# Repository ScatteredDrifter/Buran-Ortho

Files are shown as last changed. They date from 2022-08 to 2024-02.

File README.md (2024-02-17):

# Buran-Ortho
A 39-key orthogonal keyboard with support for two knobs. 

Used License :: [Cern Open hardware](/LICENSE)

---



## Status :: 
- Rev 3 released
- Case options were updated accordingly 
- untested LED-Pinout 

---

## Features :: 
- PCB supports MX, Alps and Choc v1 switches  
- QMK and Vial Support
- built with rp2040 and additional flash storage allowing for plenty of combos, layers, led matrices etc.
- easy to order with jlcpcb --> check release for files 
- support up to two encoders 
- additional pinouts for further modifications 
- - technically could fit an OLED or some other additional parts
- gasket mounted case
- case designed for 3d printing 
- several layout-options for middle part.

## Layout :: 
Below all possible layouts can be observed. All the observed layouts can be choosen and used with Vial or Qmk 

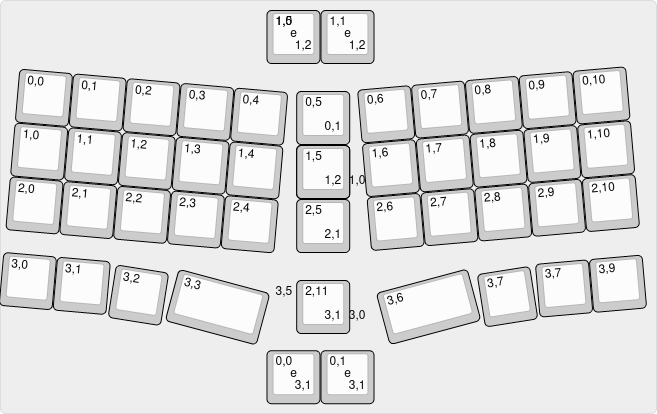
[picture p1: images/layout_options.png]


## Case :: 
All files for the case are to be found [here](/case/). 

For the top-part of the case there are several options available, where each of them was designed for a specific layout. 

Another **beautiful** case is to be found [here](https://github.com/subottimale/Buran-Bofa-case). Maybe consider it, seems to be constructed better overall.

## Firmware :: 

the pre-compiled file for Vial and the whole Qmk-userspace for this keyboard can be found [here](/firmware/)

To enter the bootloader - which is necessary in order to flash a new firmware - press the button next to the encoder on the back of the pcb and plug-it into your keyboard while keeping the button pressed. It should show up as a regular usb-stick in your file explorer now and you can drag the .utf onto this usb-stick. Once done it will restart and use your newly flashed firmware!

--- 

## Building your own :: 

On the verge to build this keyboard your own?
Below you can find a little guideline on what is required and how to obtain everything: 

### Getting PCBs ::
in the directory **production** you can find both the gerber and POS-Files required for assembly. 
I usually use JLCPCB for my prototypes, the procedure should be fairly similiar for other manufacturers however, and they require the gerber_buran_pcb.zip and for assembly of all SMD-components also their positions (buran-pos-bottom.csv) and the BOM (buran-BOM.csv) all of which can be found in the **production/assembly** directory. 

### Building Case :: 
The case consists of three parts: the bottom-part, top-part (various layouts available) and the plate. 
Print all of them yourself or have someone print them for your (JLCPCB also offers MFJ printing which could be used (**althought untested!**)).
Now to assemble the case you further need:
| Part | Quantity |
|---|---|
|2mm thick foam to use as gasket| 14x cut pieces | 
| 20mm M3 | 8x | 

> The length for the Gasket can be taken from the existing cutouts in the case 

As alternative one could also replace the screws with small 3mm diameter magnets. 

### Building the board ::
1. Prepare your pcb accordingly. 
2. Further add the plate and position your switches with them, later solder them to the pcb. 
3. add any feature, like LEDS or knobs. 
4. add **the cut foam** to each lip of the plate. It ought to be positioned both at the top and bottom of the plate --> to isolate properly from the rest of the case!
5. Position everything and screw the case together. 
6. Run Vial on your system and configure the keyboard accordingly 

## Images of Case :: 

Case-option for additional acrylic : 

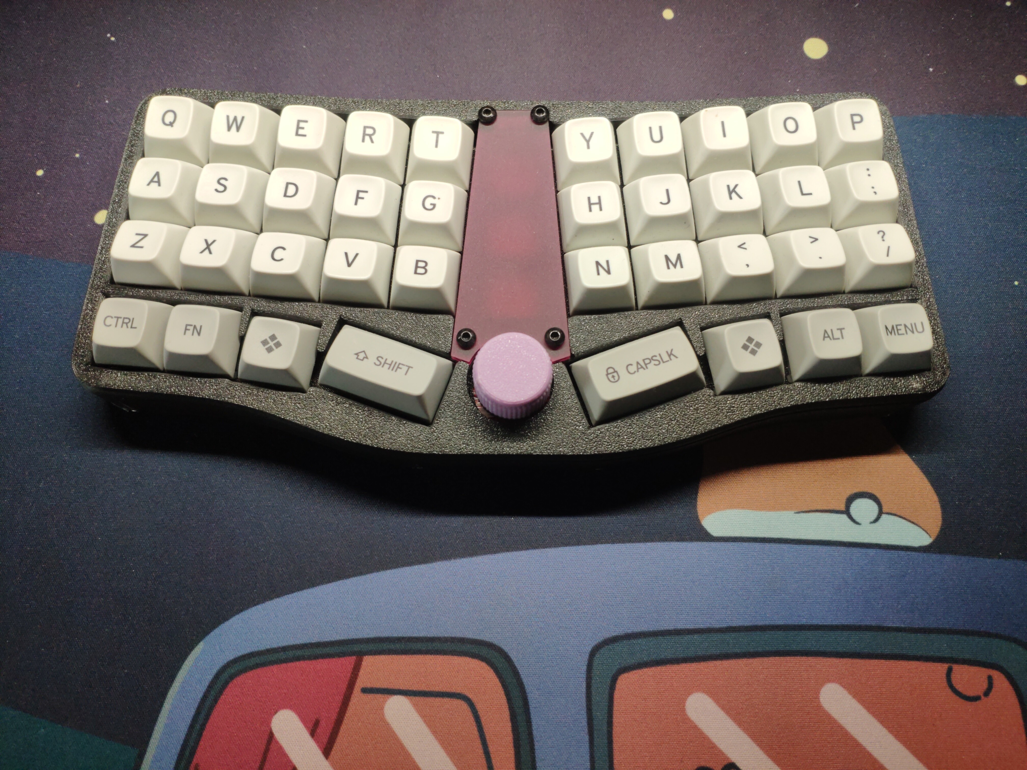
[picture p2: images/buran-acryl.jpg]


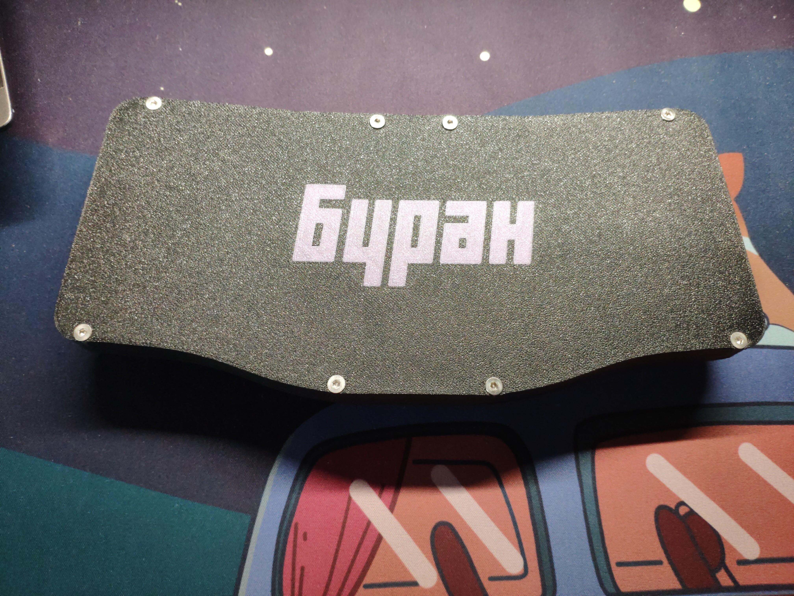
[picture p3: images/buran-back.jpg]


Case-option without additoinal buttons in the middle : 

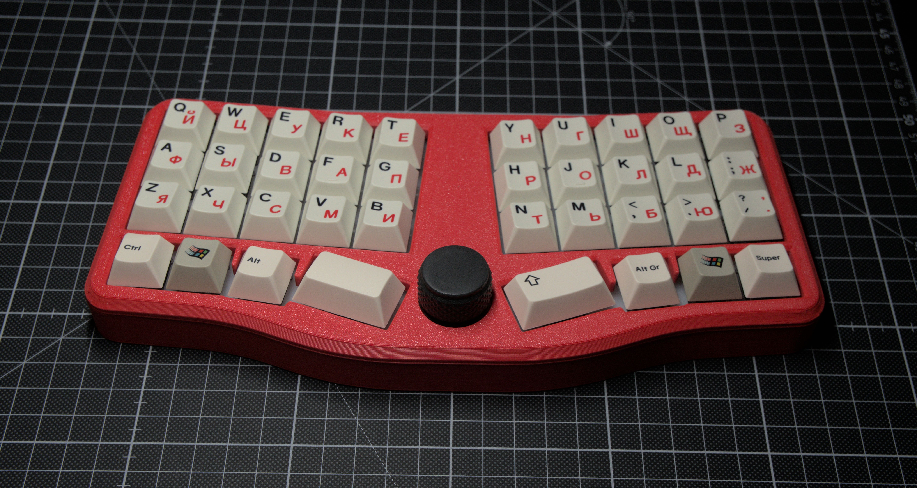
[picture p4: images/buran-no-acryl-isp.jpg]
 
Image by Isp 

Case-option with an alternative bottom design :
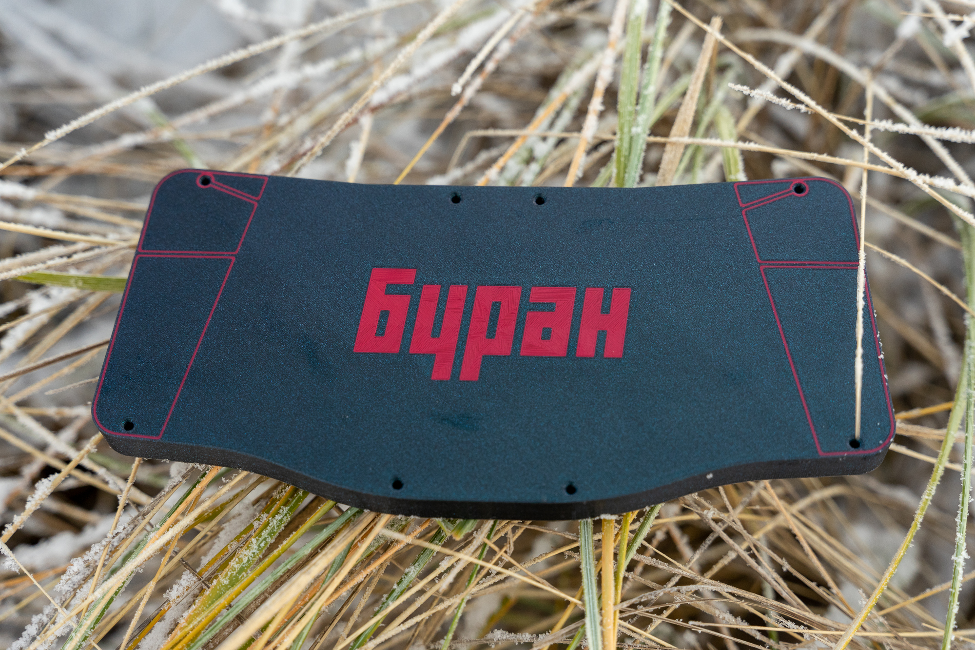
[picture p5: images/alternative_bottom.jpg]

Design and Image by DeadCatAlive

## Images of PCB :: 





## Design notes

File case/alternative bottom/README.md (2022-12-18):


Design and Image by DeadCatAlive

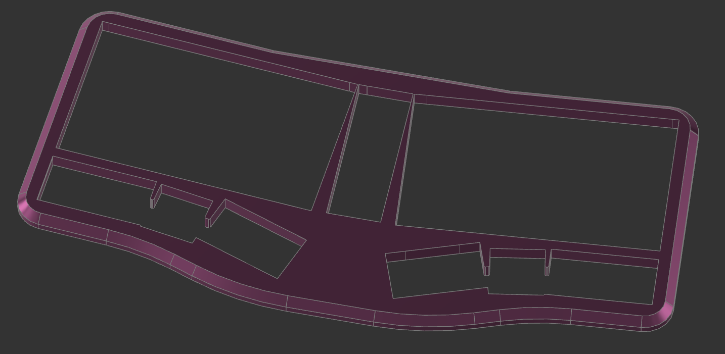
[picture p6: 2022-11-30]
images/top-options/buran_top_middleavailable.PNG

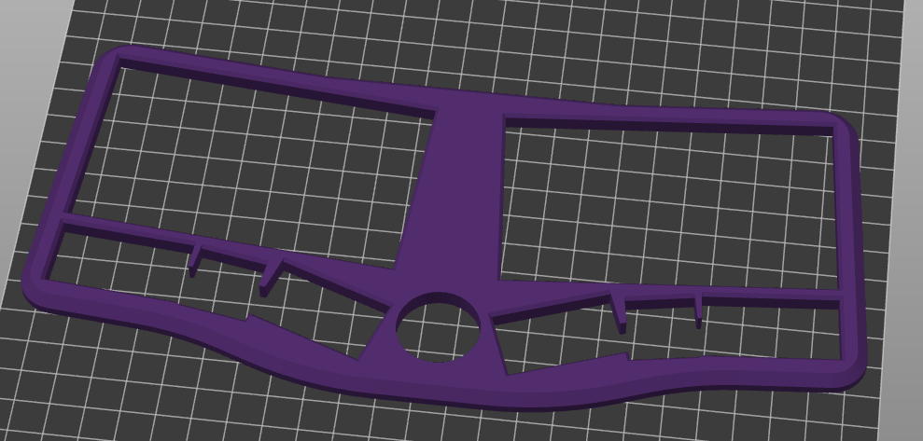
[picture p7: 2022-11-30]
images/top-options/buran_top_filled_knob.png

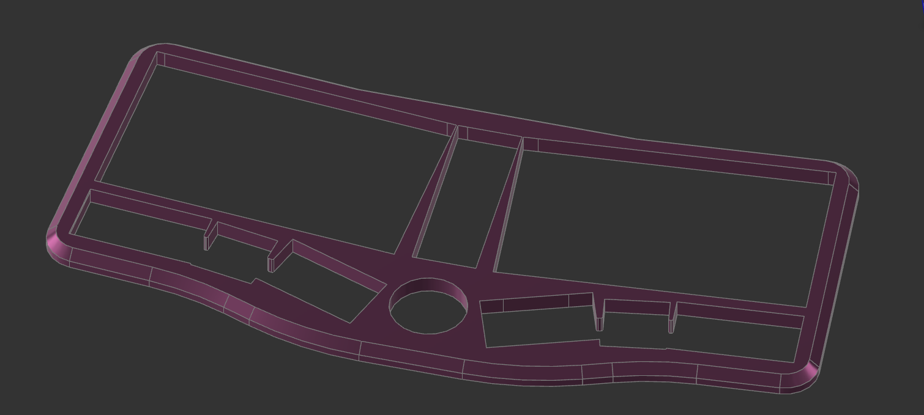
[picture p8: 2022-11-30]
images/top-options/buran_top_middleavailable_knob.PNG

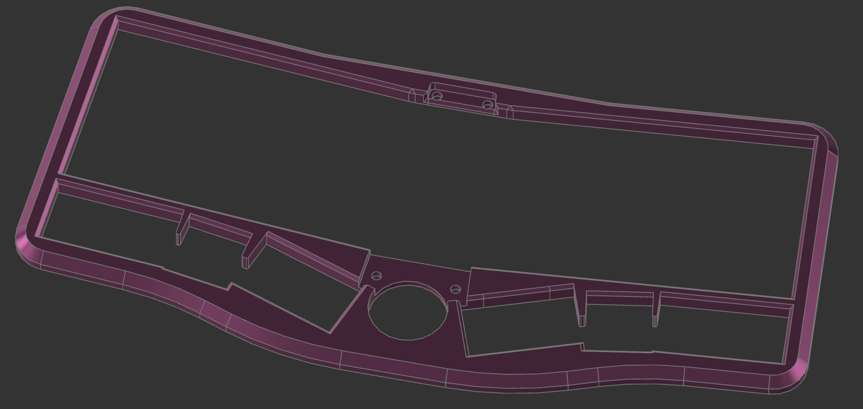
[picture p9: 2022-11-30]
images/top-options/buran_top_acrylic_free.PNG

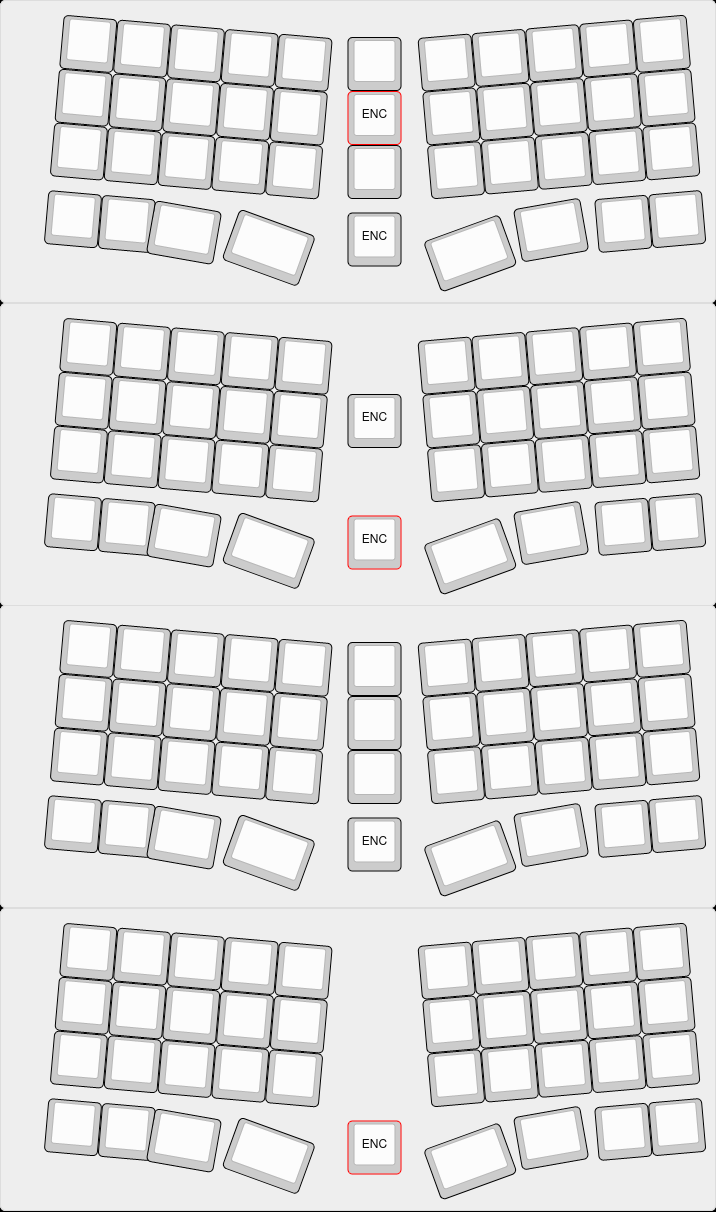
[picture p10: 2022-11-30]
images/kle_layouts.png

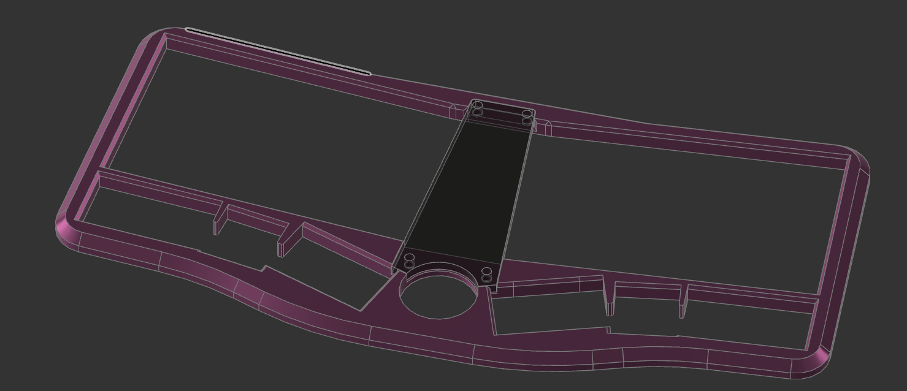
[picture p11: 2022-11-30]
images/top-options/buran_top_acrylic.PNG

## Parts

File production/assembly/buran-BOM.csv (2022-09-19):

Comment | Designator | Footprint | LCSC
10u | C1,C4,C17 | Capacitor_SMD:C_0805_2012Metric | C91245
22pf | C2,C3 | Capacitor_SMD:C_0805_2012Metric | C1804
100n | C5,C6,C7,C9,C11,C12,C13,C14 | Capacitor_SMD:C_0805_2012Metric | C49678
1u | C8,C10 | Capacitor_SMD:C_0805_2012Metric | C28323
BAV70 | D1,D2,D3,D4,D5,D6,D7,D8,D9,D10,D11,D12,D13,D14,D15,D16,D17,D18,D19,D20,D21,D22 | Package_TO_SOT_SMD:SOT-23 | C68978
polyfuse | F0 | Fuse:Fuse_1206_3216Metric | C69688
USB_C_Receptacle_USB2.0 | J0 | Connector_USB:USB_C_Receptacle_HRO_TYPE-C-31-M-12 | C165948
BREAKOUT | J1 | Connector_PinSocket_2.54mm:PinSocket_1x05_P2.54mm_Vertical
Conn_01x03_Male | J2 | Connector_PinSocket_1.27mm:PinSocket_1x03_P1.27mm_Vertical
Conn_01x01_Male | J4 | Connector_PinSocket_1.27mm:PinSocket_1x01_P1.27mm_Vertical
KEYSW | K1,K2,K3,K4,K5,K6,K7,K8,K9,K10,K11,K12,K13,K14,K15,K16,K17,K18,K19,K20,K21,K22,K23,K24,K25,K26,K27,K28,K29,K30,K31,K32,K33,K34,K35,K36,K37,K38,K39,K40,K41 | Keebio-Parts:MX-Alps-Choc-1U-NoLED
1k | R1,R5 | Resistor_SMD:R_0805_2012Metric | C115316
27 | R2,R3 | Resistor_SMD:R_0805_2012Metric | C104170
5.1k | R6,R7 | Resistor_SMD:R_0805_2012Metric | C27834
10K | R8 | Resistor_SMD:R_0805_2012Metric | C115309
RotaryEncoder_Switch | SW1,SW2 | Keebio-Parts:RotaryEncoder_EC11
SW_PUSH | SW3 | Keebio-Parts:SW_SPST_TL3342 | C318884
RESET | SW4 | Keebio-Parts:SW_SPST_TL3342 | C318884
NCP1117-3.3_SOT223 | U1 | Package_TO_SOT_SMD:SOT-223-3_TabPin2 | C26537
W25Q128JVS | U2 | Package_SO:SOIC-8_5.23x5.23mm_P1.27mm | C97521
RP2040 | U3 | cipulot_parts:RP2040-QFN-56 | C2040
SRV05-4 | U44 | Package_TO_SOT_SMD:SOT-23-6 | C85364
12MHZ Crystal | Y0 | Crystal:Crystal_SMD_3225-4Pin_3.2x2.5mm | C9002

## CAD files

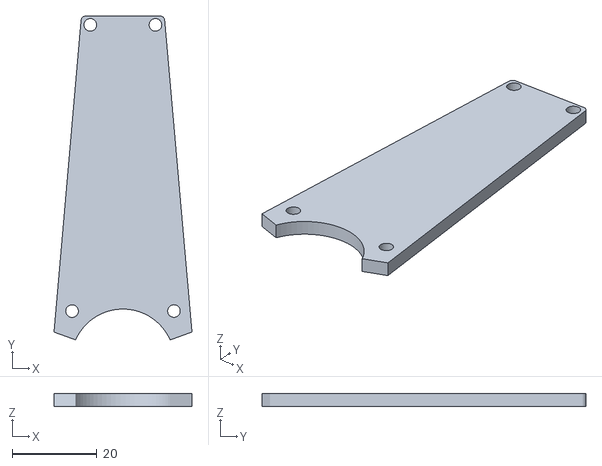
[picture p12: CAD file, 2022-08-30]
case/rev3/acrylic_complete_cover.stl
32.7 x 76.7 x 3.00

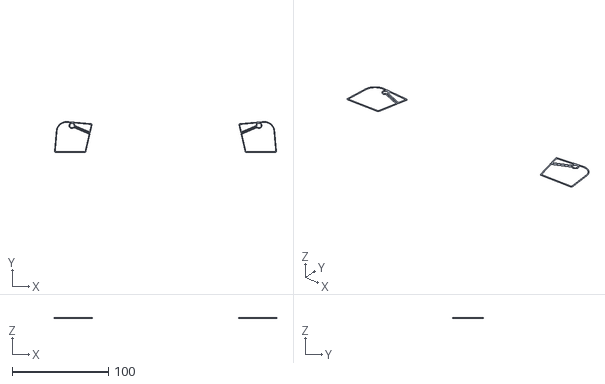
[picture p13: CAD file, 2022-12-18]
case/alternative bottom/color2.stl
230.3 x 32.0 x 0.4

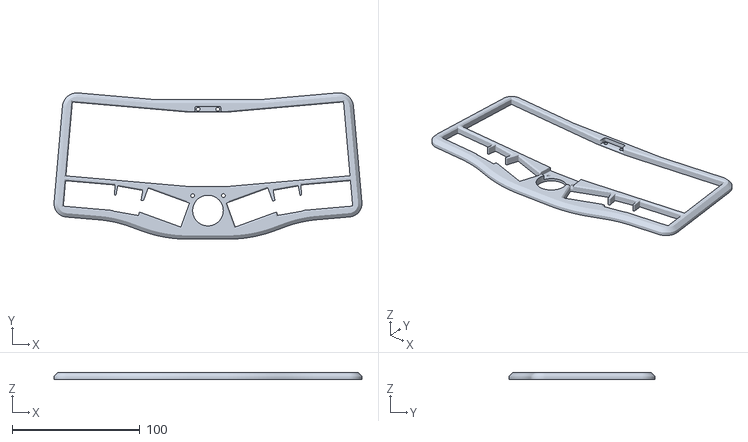
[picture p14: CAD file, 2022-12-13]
case/rev3/higherQualityExport/top_acrylic.stl
241.4 x 114.8 x 5.60

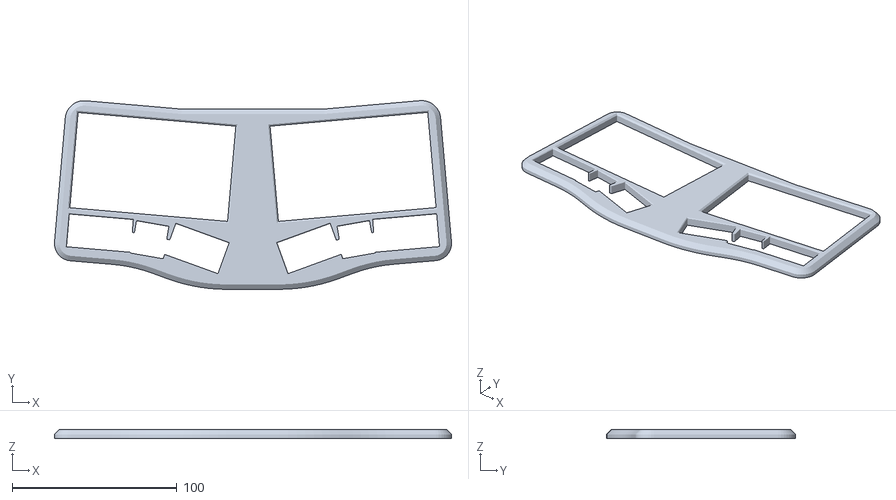
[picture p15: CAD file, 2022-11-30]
case/rev3/top_closed.stl
241.3 x 114.7 x 5.60

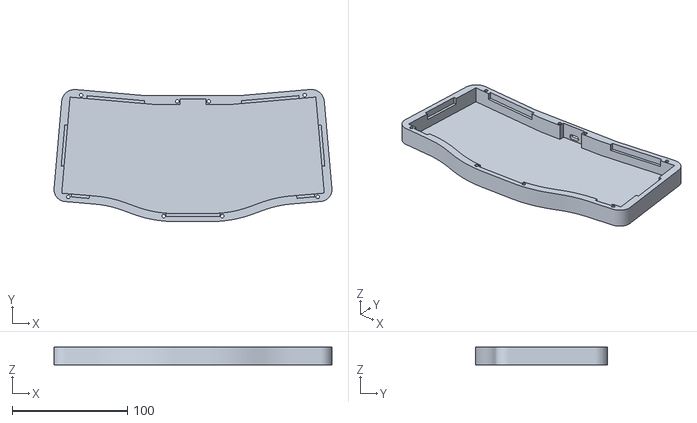
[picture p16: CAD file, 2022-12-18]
case/alternative bottom/bottom_case.stl
241.4 x 114.8 x 15.6

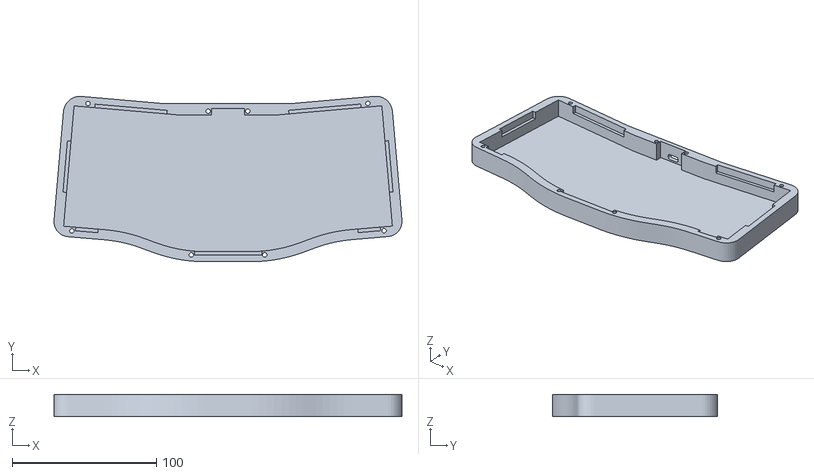
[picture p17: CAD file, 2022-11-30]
case/rev3/bottom_case.stl
241.3 x 114.7 x 15.6

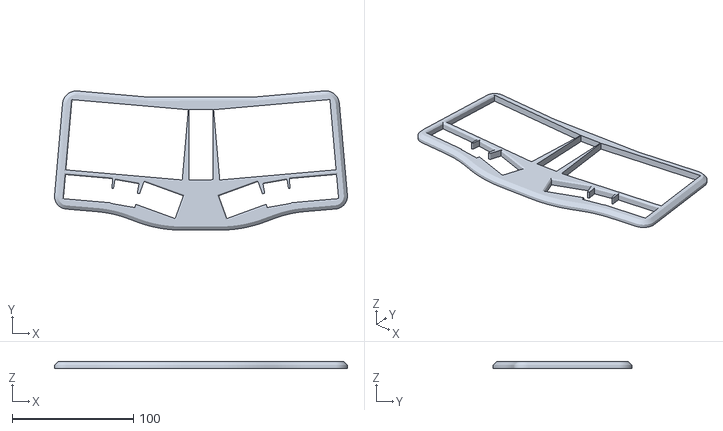
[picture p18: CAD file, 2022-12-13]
case/rev3/higherQualityExport/top_middle_available_no_knob.stl
241.4 x 114.8 x 5.60

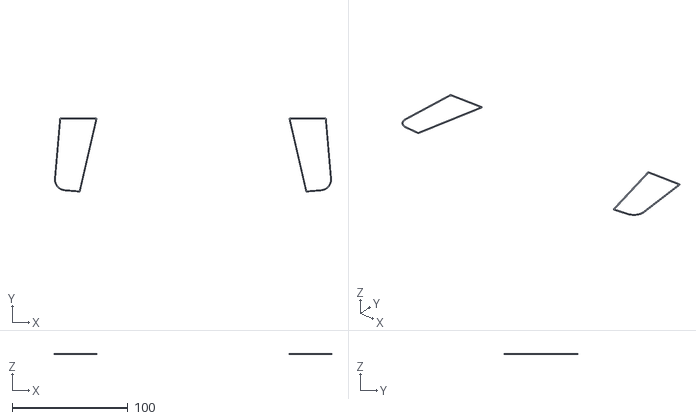
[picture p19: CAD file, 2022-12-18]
case/alternative bottom/color1.stl
239.8 x 64.0 x 0.4

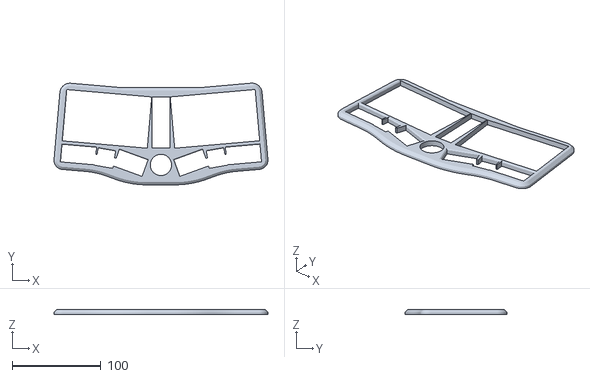
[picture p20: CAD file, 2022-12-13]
case/rev3/higherQualityExport/top_middle_available_knob.stl
241.4 x 114.8 x 5.60

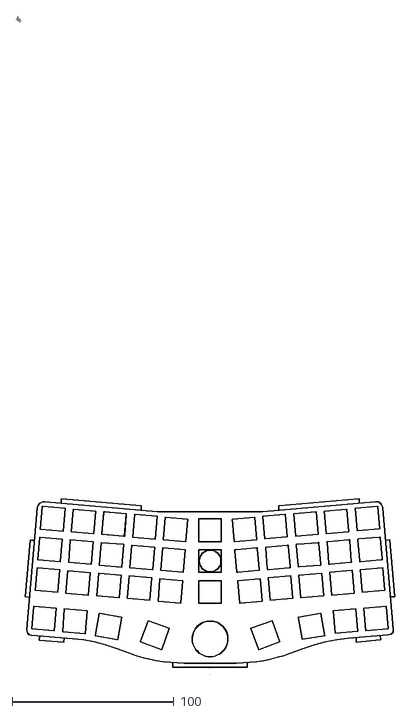
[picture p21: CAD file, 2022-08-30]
case/rev3/plate_sketch.dxf
233.9 x 406.6

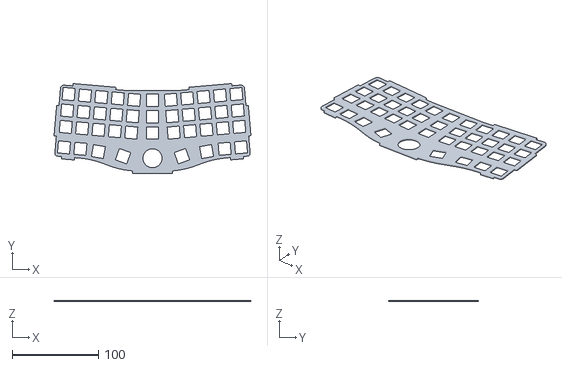
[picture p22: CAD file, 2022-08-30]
case/rev3/plate_no_tolerance.stl
228.2 x 104.2 x 1.60

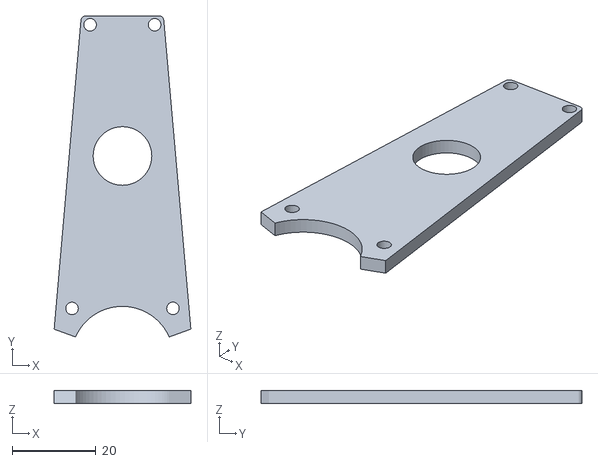
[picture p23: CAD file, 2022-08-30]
case/rev3/acrylic_top_hole.stl
32.7 x 76.7 x 3.00

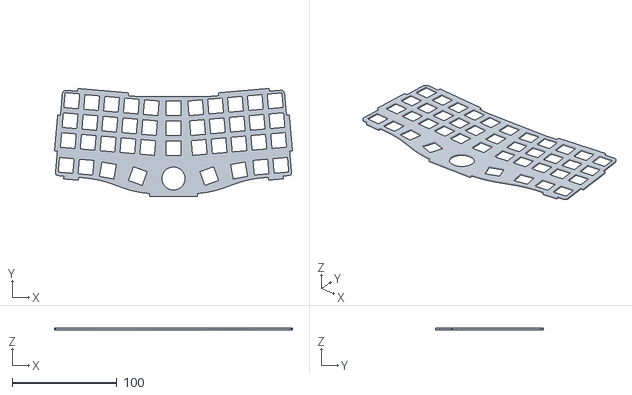
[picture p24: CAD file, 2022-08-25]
case/rev3/plate_tolerances.stl
227.4 x 103.4 x 1.60

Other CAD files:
case/rev3/top_acrylic_hole_knob.stl
case/alternative bottom/bottom_case_font.stl
case/rev3/higherQualityExport/top_closed.stl
case/rev3/top_closed_knob.stl
case/rev3/top_noAcrylic_middle_knob.stl

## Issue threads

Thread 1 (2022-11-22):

Switches

neisinger, 2022-11-22:
what kind of switches are possible with the buran?

ScatteredDrifter, 2022-12-01:
Heya, sorry for answering that late,  i somehow skipped your message!

The pcb supports Mx, Alps and Choc v1 switches, however the current Case was only built around Mx-Switches.
For alps you would require a new plate, which i could release within few days

Closed 2022-12-02.

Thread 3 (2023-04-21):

KiCad nor JLCPCB opens the GERBER zip.

ChaosSys1312, 2023-04-21:
The title is simple enough, but JLCPCB does not recognize the most recent PCBs zip file, stating several issues within the GERBER viewer, and kicads GERBER viewer throws errors at me too. I'm wrapping up for the night so I can't post the best details right now, but I can provide those tomorrow if necessary.

Closed 2023-04-22.

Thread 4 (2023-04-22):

Help with assembly files

Perisys1312, 2023-04-22:
JLCPCB, using the "buran-BOM.csv" and "buran-pos-bottom.csv" files for BOM and CPL respectively, and the gerber-buran-pcb.zip for the gerber file, all from the repository and not release files, align themselves weirdly and I'm unsure if it's safe to order. I'd like some help on how to order and do this properly, if possible.

Edit: I manually readjusted them myself following the kicad project very closely.

ScatteredDrifter, 2023-05-01:
Hey, Sorry for responding so late, I barely notice the messages here, excuse me!
Jlcs preview is a little weird and usually they will be aligned again once they've put them into production, review to be specific.
Readjusting them is also possible, yet I haven't put effort into it yet.

ChaosSys1312, 2023-05-02:
> Hey, Sorry for responding so late, I barely notice the messages here, excuse me! Jlcs preview is a little weird and usually they will be aligned again once they've put them into production, review to be specific. Readjusting them is also possible, yet I haven't put effort into it yet.

That's alright! Thank you regardless, another question while I'm here, do you have any suggestions as to where I should print the plate? It's too thin for JLCPCB to accept it.
And also, is the thickness of the plate flexible with the case design, because if so I might thicken them in a 3D editor, or just get them printed as FR4 instead.

Perisys1312, 2023-05-14:
I forgot to account for conversion, JLC requires 1cm thickness minimum for 3D printing, I'll use FR4 instead because it feels much better in my opinion. My apologies

Closed 2023-05-14.

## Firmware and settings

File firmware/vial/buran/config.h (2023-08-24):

// Copyright 22 ScatteredDrifter / fabiansta

#pragma once

#include "config_common.h"

/* --- USB Device properties --- */
#define VENDOR_ID 0xFAB0
#define PRODUCT_ID 0xFAB1
#define DEVICE_VER 0x0001
#define MANUFACTURER ScatteredDrifter
#define PRODUCT Буран

/* --- Matrix definition --- */
#define MATRIX_ROWS 4 
#define MATRIX_COLS 12

/* --- Matrix assignment --- */ 
#define MATRIX_COL_PINS \
    { GP7, GP8, GP9, GP11, GP10, GP0, GP17, GP18, GP19, GP20, GP21, GP16}
#define MATRIX_ROW_PINS \
    { GP6, GP13, GP14, GP15 }
/* --- Encoder assignment --- */
#define ENCODER_RESOLUTION 4

/* --- additional settings --- */
#define DEBUG_MATRIX_SCAN_RATE
#define LAYER_STATE_16BIT
// reducing chattering, set to 0 if not necessary 
#define DEBOUNCE 5 
#define DIODE_DIRECTION COL2ROW


//#define QMK_WAITING_TEST_BUSY_PIN GP8
//#define QMK_WAITING_TEST_YIELD_PIN GP9

/* --- RP2040 specific settings */
#define RP2040_BOOTLOADER_DOUBLE_TAP_RESET
//#define RP2040_BOOTLOADER_DOUBLE_TAP_RESET_LED GP25
#define RP2040_BOOTLOADER_DOUBLE_TAP_RESET_TIMEOUT 500U

#define RGB_DI_PIN GP12

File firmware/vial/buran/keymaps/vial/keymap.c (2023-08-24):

/* Derivate of elmo's firmware >>kb-elmo<mail@elmo.space>
 *
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
 * You should have received a copy of the GNU General Public License
 * along with this program.  If not, see <http://www.gnu.org/licenses/>.
 */
#include QMK_KEYBOARD_H


const uint16_t PROGMEM keymaps[][MATRIX_ROWS][MATRIX_COLS] = {

/* Buran
   *  ┌────┬────┬────┬────┬────┐┌────┐┌────┬────┬────┬────┬────┐
   *  │ Q  │ W  │ E  │ R  │ T  ││    ││ Y  │ U  │ I  │ O  │ P  │
   *  ├────┼────┼────┼────┼────┤├────┤├────┼────┼────┼────┼────┤
   *  │ A  │ S  │ D  │ F  │ G  ││    ││ H  │L(2J│ K  │ L  │ ;  │
   *  ├────┼────┼────┼────┼────┤├────┤├────┼────┼────┼────┼────┤
   *  │ Z  │ X  │ C  │ V  │ B  ││    ││ N  │ M  │ ,  │ .  │ /  │  
   *  └────┴────┴────┴────┴────┘└────┘└────┴────┴────┴────┴────┘
   *  ┌────┬────┬─────┐┌──────┐ ┌────┐ ┌──────┐┌─────┬────┬────┐
   *  │ctrl│MO1 │ GUI ││LT1Spc│ │MCR │ │ Bksp ││Ralt │Mo1 │ctrl│                                 
   *  └────┴────┴─────┘└──────┘ └────┘ └──────┘└─────┴────┴────┘
   */
   [0] = LAYOUT(
            
        KC_Q,    	KC_W,    	KC_E,    	KC_R,    	KC_T,  		KC_NO,    	KC_Y,    	KC_U,    	KC_I,    	KC_O,    	KC_P,    
        KC_A,    	KC_S,    	KC_D,    	KC_F,    	KC_G, 		KC_NO,    	KC_H,    	KC_J,    	KC_K,    	LT(2,KC_L),  KC_SCOLON,
	    KC_Z,    	KC_X,    	KC_C,    	KC_V,    	KC_B, 		KC_NO,    	KC_N,    	KC_M,    	KC_COMMA,    	KC_DOT,    	KC_SLASH,
        KC_LCTRL,      	MO(1),    	KC_LGUI, 	LT(0,KC_SPACE),   		KC_NO,    			KC_BSPACE, 	KC_RALT,    	MO(1),	 	KC_LSHIFT
	
    ),
/* Buran
   *  ┌────┬────┬────┬────┬────┐┌────┐┌────┬────┬────┬────┬────┐
   *  │ 0  │ 1  │ 2  │ 3  │ 4  ││    ││ 5  │ 6  │ 7  │ 8  │ 9  │ 
   *  ├────┼────┼────┼────┼────┤├────┤├────┼────┼────┼────┼────┤
   *  │ESC │ [  │ ]  │ \  │ '  ││    ││LEFT│DOWN│ UP │RGHT│    │
   *  ├────┼────┼────┼────┼────┤├────┤├────┼────┼────┼────┼────┤
   *  │SHFT│    │ `  │ -  │ =  ││    ││ `  │    │ @  │ '  │ /  │  
   *  └────┴────┴────┴────┴────┘└────┘└────┴────┴────┴────┴────┘
   *  ┌────┬────┬─────┐┌──────┐ ┌────┐ ┌──────┐┌─────┬────┬────┐
   *  │lalt│    │     ││      │ │    │ │ del  ││     │    │    │                                 
   *  └────┴────┴─────┘└──────┘ └────┘ └──────┘└─────┴────┴────┘
  */
   [1] = LAYOUT(
            
        KC_1,    	KC_2,    	KC_3,    	KC_4,    	KC_5,  			KC_NO,    	KC_6,    	KC_7,    	KC_8,    	KC_9,    	KC_0,    
        KC_ESC,    	KC_LBRC,    	KC_RBRC,    	KC_BSLS,    	KC_QUOT, 		KC_NO,    	KC_LEFT,    	KC_DOWN,    	KC_UP,    	KC_RIGHT,    	KC_NO,
	    KC_LSFT,    	KC_NO,    	KC_QUOT,    	KC_MINS,    	KC_EQL, 		KC_NO,    	KC_QUOT,    	KC_NO,    	LSFT(KC_2),    	KC_GRV,    	KC_SLASH,
        KC_LALT,      	KC_NO,    	KC_NO, 		KC_NO,   				KC_NO,    			KC_DEL, 	KC_NO,    	KC_NO, 	KC_NO
	
    ),
 /*Buran
   *  ┌────┬────┬────┬────┬────┐┌────┐┌────┬────┬────┬────┬────┐
   *  │ F1 │ F2 │ F3 │ F4 │    ││    ││    │    │    │    │    │ 
   *  ├────┼────┼────┼────┼────┤├────┤├────┼────┼────┼────┼────┤
   *  │ F5 │ F6 │ F7 │ F8 │    ││    ││    │    │    │    │    │
   *  ├────┼────┼────┼────┼────┤├────┤├────┼────┼────┼────┼────┤
   *  │ F9 │F10 │F11 │F12 │    ││    ││    │    │    │    │    │  
   *  └────┴────┴────┴────┴────┘└────┘└────┴────┴────┴────┴────┘
   *  ┌────┬────┬─────┐┌──────┐ ┌────┐ ┌──────┐┌─────┬────┬────┐
   *  │VOLU│VOLD│MUTE ││BRIGHT│ │    │ │      ││     │    │    │                                 
   *  └────┴────┴─────┘└──────┘ └────┘ └──────┘└─────┴────┴────┘
   */
   [2] = LAYOUT(
            
        KC_F1,    	KC_F2,    	KC_F3,    	KC_F4,    	KC_NO,  	KC_NO,    	KC_NO,    	KC_NO,    	KC_NO,    	KC_NO,    	KC_NO,    
        KC_F5,    	KC_F6,    	KC_F7,    	KC_F8,    	KC_NO, 		KC_NO,    	KC_NO,    	KC_NO,    	KC_NO,    	KC_NO,    	KC_NO,
	    KC_F9,    	KC_F10,    	KC_F11,    	KC_F12,    	KC_NO, 		KC_NO,    	KC_NO,    	KC_NO,    	KC_NO,    	KC_NO,    	KC_NO,
        KC_NO,      KC_NO,    	KC_NO, 		KC_NO,   			    KC_NO,    		        KC_NO, 		KC_NO,    	KC_NO, 		KC_NO
	
    ),

    [3] = LAYOUT(

        KC_NO,    	KC_NO,    	KC_NO,    	KC_NO,    	KC_NO,  	KC_NO,    	KC_NO,    	KC_NO,    	KC_NO,    	KC_NO,    	KC_NO,
        KC_NO,    	KC_NO,    	KC_NO,    	KC_NO,    	KC_NO, 		KC_NO,    	KC_NO,    	KC_NO,    	KC_NO,    	KC_NO,    	KC_NO,
        KC_NO,    	KC_NO,    	KC_NO,    	KC_NO,    	KC_NO, 		KC_NO,    	KC_NO,    	KC_NO,    	KC_NO,    	KC_NO,    	KC_NO,
        KC_NO,      KC_NO,    	KC_NO, 		KC_NO,   			    KC_NO,    		        KC_NO, 		KC_NO,    	KC_NO, 		KC_NO

    ),
    
    [4] = LAYOUT(

        KC_NO,    	KC_NO,    	KC_NO,    	KC_NO,    	KC_NO,  	KC_NO,    	KC_NO,    	KC_NO,    	KC_NO,    	KC_NO,    	KC_NO,
        KC_NO,    	KC_NO,    	KC_NO,    	KC_NO,    	KC_NO, 		KC_NO,    	KC_NO,    	KC_NO,    	KC_NO,    	KC_NO,    	KC_NO,
        KC_NO,    	KC_NO,    	KC_NO,    	KC_NO,    	KC_NO, 		KC_NO,    	KC_NO,    	KC_NO,    	KC_NO,    	KC_NO,    	KC_NO,
        KC_NO,      KC_NO,    	KC_NO, 		KC_NO,   			    KC_NO,    		        KC_NO, 		KC_NO,    	KC_NO, 		KC_NO

    ),
    
    [5] = LAYOUT(

        KC_NO,    	KC_NO,    	KC_NO,    	KC_NO,    	KC_NO,  	KC_NO,    	KC_NO,    	KC_NO,    	KC_NO,    	KC_NO,    	KC_NO,
        KC_NO,    	KC_NO,    	KC_NO,    	KC_NO,    	KC_NO, 		KC_NO,    	KC_NO,    	KC_NO,    	KC_NO,    	KC_NO,    	KC_NO,
        KC_NO,    	KC_NO,    	KC_NO,    	KC_NO,    	KC_NO, 		KC_NO,    	KC_NO,    	KC_NO,    	KC_NO,    	KC_NO,    	KC_NO,
        KC_NO,      KC_NO,    	KC_NO, 		KC_NO,   			    KC_NO,    		        KC_NO, 		KC_NO,    	KC_NO, 		KC_NO

    ),

    [6] = LAYOUT(

        KC_NO,    	KC_NO,    	KC_NO,    	KC_NO,    	KC_NO,  	KC_NO,    	KC_NO,    	KC_NO,    	KC_NO,    	KC_NO,    	KC_NO,
        KC_NO,    	KC_NO,    	KC_NO,    	KC_NO,    	KC_NO, 		KC_NO,    	KC_NO,    	KC_NO,    	KC_NO,    	KC_NO,    	KC_NO,
        KC_NO,    	KC_NO,    	KC_NO,    	KC_NO,    	KC_NO, 		KC_NO,    	KC_NO,    	KC_NO,    	KC_NO,    	KC_NO,    	KC_NO,
        KC_NO,      KC_NO,    	KC_NO, 		KC_NO,   			    KC_NO,    		        KC_NO, 		KC_NO,    	KC_NO, 		KC_NO

    ),
    
    [7] = LAYOUT(

        KC_NO,    	KC_NO,    	KC_NO,    	KC_NO,    	KC_NO,  	KC_NO,    	KC_NO,    	KC_NO,    	KC_NO,    	KC_NO,    	KC_NO,
        KC_NO,    	KC_NO,    	KC_NO,    	KC_NO,    	KC_NO, 		KC_NO,    	KC_NO,    	KC_NO,    	KC_NO,    	KC_NO,    	KC_NO,
        KC_NO,    	KC_NO,    	KC_NO,    	KC_NO,    	KC_NO, 		KC_NO,    	KC_NO,    	KC_NO,    	KC_NO,    	KC_NO,    	KC_NO,
        KC_NO,      KC_NO,    	KC_NO, 		KC_NO,   			    KC_NO,    		        KC_NO, 		KC_NO,    	KC_NO, 		KC_NO

    ),
    
    
    


};
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

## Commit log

2022-08-16 updated files, fixed wrong LDO, fuckup of protection
    [buran_BOM.csv, final-pcb-positions.dxf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]
2022-08-16 updated schematic, tidying up
    [knobdeavour.kicad_sch]
2022-08-16 updated pcb, added second btn
    [knobdeavour.kicad_sch]
2022-08-25 updated case and images
    [acrylic_complete_cover.stl, acrylic_hole_middle.dxf, acrylic_hole_middle.stl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]
2022-08-30 updated case, including plate
    [acrylic_complete_cover.stl, acrylic_hole_middle.dxf, acrylic_hole_middle.stl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]
2022-08-30 fixed plate sketch:
    [plate_sketch.dxf]
2022-09-07 updated case
    [top-closed.stl, top_case_without_acrylic.stl]
2022-09-19 updated case, readme, images
    [bottom_case.stl, bottom_case_font.stl]
2022-09-19 updated gerber, readme :
    [buran-BOM.csv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]
2022-09-20 updated firmware, fixed by Ivo/ISP
    [config.h, keymap.c]
2022-11-30 updated Pcb and production files.
    - added two additional breakouts for GPIO pins > next to Encoder
    - replaced pin-breakout for Leds with larger 2.54mm pin-sockets for
    easier soldering
    [bottom_case.stl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]
2022-12-01 updated README
    - added information about supported switches
2022-12-13 added higher quality exports of case
    [top_acrylic.stl, top_closed.stl, top_middle_available_knob.stl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]
2022-12-17 Added case, images and readme file, updated main readme
    [bottom_case.stl, bottom_case_font.stl, color1.stl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]
2023-06-20 Fixed rotary encoders and cleaned up code
    [config.h, keymap.c]
2024-02-17 Update README.md, add link to alternative case

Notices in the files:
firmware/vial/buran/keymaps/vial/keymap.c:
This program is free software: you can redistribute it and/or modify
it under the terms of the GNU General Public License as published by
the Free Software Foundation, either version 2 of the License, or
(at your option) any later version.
